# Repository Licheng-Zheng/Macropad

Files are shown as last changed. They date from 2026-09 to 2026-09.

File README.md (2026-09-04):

#### Overview
A custom 9-key mechanical macropad with an OLED display and joystick that is very programmable. It acts as a "Rubber Ducky" which is used to send in commands as if it were a keyboard without relying on any external hardware. 
- Can send multi-character macros entirely on-device without using software like AutoHotkey 
- Key to 81 distinct macro assignments, across 9 different modes 
- OLED display to show the node, joystick position and key presses 
- Under $20 dollars in prorated (I only count a proportion of a cost if I only use a portion of the materials) materials. 
  - If you are looking at this, you probably already have some basic materials at home like wires and raspberry pi picos, so it will likely be significantly cheaper. I only had to spend 5 dollars for this project, and that was because I melted my first raspberry pi. 

 

#### Hardware Limitations 
Because this device is a usb device, they can only send in key presses at the rate that your USB polls. For example, I currently have mine set up to quickly type in a file path that I use frequently, and it takes a couple milliseconds for it to type out. This is due to the fact that USB devices aren't able to paste in things (I think it is due to security reasons). Keyboards can only use the HID protocol, which sends one command every USB polling cycle.  
- To bypass this, you can try using a tool like AutoHotkey, bind one of the keys on the macropad to a key not on the keyboard (F13 to F21), and have it send the command instantly using software. However, in this case, the macropad will only work when that particular software is downloaded on your computer. 
- I personally am ok with the macropad typing everything out, and I would prefer if the macropad didn't rely on a software on my computer to function, so I am just keeping it as is.
- Commercial macropads use software similar to AutoHotkey to send commands, but their softwares are significantly better and have more functionality (opening apps) 

#### Editing the functionality of the Macropad 
1. Changing Keys 
Locate the `MACRO_STRINGS[9][9]` - 9 Lists, each with 9 items. This basically means there are 9 presets, each can have 9 different commands. Mkae sure you are changing it for the right profile.
```
const char* MACRO_STRINGS[9][9] = {
    // Profile 0 (Example: Git Workflow)
    {
        "git status\n", "git add .\n", "git commit -m \"Update\"\n",
        "git push\n",   "git pull\n",  "clear\n",
        "",             "",            ""
    },
```
- You would just type in what string you want the macropad to send in. To press enter, put a `\n` (newline character) after it. 
- You can leave things empty with `""`, and it will just display "UNASSIGNED_KEY" on the OLED screen (nothing gets sent to computer)

2. Changing the Profile Names
There are 9 different possible profiles. 
```
const char* MODE_NAMES[9] = {
    "MODE: EMACS", "MODE: NUMPAD", "MODE: CUSTOM 3", 
    "MODE: CUSTOM 4", "MODE: CUSTOM 5", "MODE: CUSTOM 6", 
    "MODE: CUSTOM 7", "MODE: CUSTOM 8", "MODE: CUSTOM 9"
};
```
You can also change the profile selection in the `MODE_SELECTION_MAP`, but as long as you set up the names properly, this isn't necessary. (also makes it a lot more complicated)

**Chords** 
This is super important, this is how you switch different modes. All three keys must be pressed simultaneously to send teh command. 
- Top row: Recalibrate the joystick 
  - THis polls the joystick 20 times in a couple milliseconds to find where its resting state is at. This then becomes the new "middle" this is helpful if the joystick is slightly off from the middle of `2048`. There is a "deadzone" of 150 where if it is less than 150 away from the middle, no output is registered. 
- Middle row: Turn joystick on or off. 
  - When my soldering wasn't good enough, the joystick would jump around, which would move the mouse around. In case that happens during something important, you can toggle the joystick on or off here. 
- Bottom row: Opens the "Select Profile 1-9" menu, where you can then hit another key to select that particular profile.
- Rightmost column: Turns on the bootloader. 
  - This is essentially you plugging it back in with the bootsel button pressed. It allows it to accept code. 
  - This allows you to upload code without having to open the case again. 
  - Note that this won't work if the raspberry pi pico has crashed (this hasn't happened to me, so not sure what happens next from there)

#### Pinout 
This is how everything needs to be soldered, try not to use much more wire than required, because this makes the case very hard to close. For it to fit in the case that I modelled, headers will need to be removed. 

 

| Component | Module Pin | Pico Connection (GPIO) | Pico Physical Pin | Notes |
| --- | --- | --- | --- | --- |
| **OLED Display** | SDA | GP0 | 1 | I2C0 SDA |
|  | SCL | GP1 | 2 | I2C0 SCL |
|  | VCC | 3V3(OUT) | 36 |  |
|  | GND | GND | 38 |The raspberry pi pico has multiple grounds that can be used |
| **Analog Joystick** | VRx (Horz) | GP26 | 31 | ADC Channel 0 |
|  | VRy (Vert) | GP27 | 32 | GP28 can also be used (for this one or VRx) if the pin is damaged. These are the only pins that can be used because the rapsberry pi pico only has 3 analog pins (the pins that can interpret an analog signal) |
|  | VCC / + | 3V3(OUT) | 36 | Do not use 5V VBUS. This will deliver more power than the joystick can handle and will probably lead to either the joystick or the pico board not functioning anymore |
|  | GND / - | GND | 33 |  |
| **Mechanical Keys** | Top Left | GP9 | 12 | Route the second pin of every switch to a common Ground (GND). This is called daisy chaining. |
|  | Top Middle | GP10 | 14 | For keyboards with more keys, matrices are used with one way diodes. Because we only have 9 mechanical switches and our raspberry pi has more than enough GPIO pins, we don't need to do this.  |
|  | Top Right | GP11 | 15 |  |
|  | Middle Left | GP6 | 9 |  |
|  | Center | GP7 | 10 |  |
|  | Middle Right | GP8 | 11 |  |
|  | Bottom Left | GP3 | 5 |  |
|  | Bottom Middle | GP4 | 6 |  |
|  | Bottom Right | GP5 | 7 |  |

#### CAD Files
These were printed out on my ENder 3 V2 uising white PLA. FOr more details on 3D printing these parts, see `3D_printing_information.md`
Here is the link to the onshape file, details for the purpose of each piece is also found in `3D_printing_information.md`: https://cad.onshape.com/documents/84586ac2eb88b3ac68ec06c5/w/5dcf2d6096f851e748bc3f74/e/13d985377aa5300de055461e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

The STL_Files is for people who don't want to see the models in Onshape and want to print immediately. Some orientation might be required, see `3D_printing_information.md` for how I oriented it. 

I will not be providing my `.uf2` file because everyones needs for a macropad are different, and it requires modifying the `main.cpp` file in order to change its functionality. I will try to create a guide to compiling it for the first time and changing the code. 
For initial testing, I will include the `.uf2` file with just the numpad enabled. 

#### Troubleshooting Guide 
Some of the harder to fix issues that I encountered while making this: 
1. Keys are not mapped properly
   - If they are all sending commands, it means you didn't solder it to the pin outlined in the pinout table above. Fear not!! You can change it in the software so you don't have to resolder anything. You can map the GPIO pin to the correct key switch in `const uint KEY_PINS[9] = {9, 10, 11, 6, 7, 8, 3, 4, 5}; `. 
   - I recommend going into the numpad mode, pressing all the keys (in order), and make the swaps accordingly. 
2. Joystick keeps on dropping lower and lower
   - This meant that my wires were not properly connected to the pico, so the voltage was not getting sent over properly. 
   - Try reseating your wires (heating it up until liquid, and then letting it cool again)
   - I also replaced my first joystick, not sure if that was the issue, but if the carbon track the joystick uses to send its signal to the raspberry pi is broken, the signal will also not work properly 
3. The case is not closing
   - Try unsoldering the wire, cutting it a bit shorter, and make sure they are grouped with similar cables. (I did it where each row of keys had its own bundle) 
   - Use tape to secure it to the bottom of the macropad so it won't get into the way of the spacers that connect the top and bottom halves. 
4. Raspberry pi port doesn't fit into its hole
   - There is a big overhang right above where the port goes, so there is palstic blocking the port from reaching into the hole. 
   - Use a knife to cut away some of the overhanging plastic to get it to fit. Also, only use two screws to hold the raspberry pi pico in, it is more than enough

There are many more issues that I encountered, but the brain has blocked out the trauma and I can't remember some of the issues anymore. 

#### Bill of Materials
| Item | Qty | Description | Cost |
| --- | --- | --- | --- |
| **Raspberry Pi Pico** | 1 | Standard RP2040 microcontroller | $5.00 |
| **Mechanical Switches** | 9 | MX-style switches (Prorated from an $11 50-pack) | $1.98 |
| **Keycaps** | 9 | Numpad keys scavenged from a standard $11 keycap set | ~$2.00 |
| **Analog Joystick Module** | 1 | Standard 5-pin thumbstick module | $3.00 |
| **OLED Display** | 1 | 0.96" 128x64 I2C OLED (SSD1306) | $3.00 |
| **Wire** | 1 | Spool of 28 AWG wire | $3.00 |
| **Fasteners** | 24 | 12x M2 heat set inserts and 12x M2 screws | Scavenged / Assorted |
| **3D Printer Filament** | 96g | PLA at $17/kg. *(Anglers: 8.96g, Top Plate: 23.04g, Bottom Plate: 63.38g, Test Plate: 0.64g)* | $1.63 |
| **USB Cable** | 1 | Data-capable micro-USB cable (Reused from an old phone) | $0.00 ($4.00 new) |
| **Total Prorated Cost** |  |  | **~$19.61** |

The keycaps can also be 3d printed, the stem might is pretty weak and it definitely won't look as great.
This is the printed one I used first which worked pretty well: https://www.printables.com/model/109679-cherry-mx-low-profile-keycap

Hardware lost along the way, you will be remembered: 
- A raspberry pi pico
  - Melted the bootsel button while trying to solder on the ground wire
- A joystick
  - X kept on jumping around. I thought it was due to the carbon track breaking, but it may have been because my wiring was wrong.

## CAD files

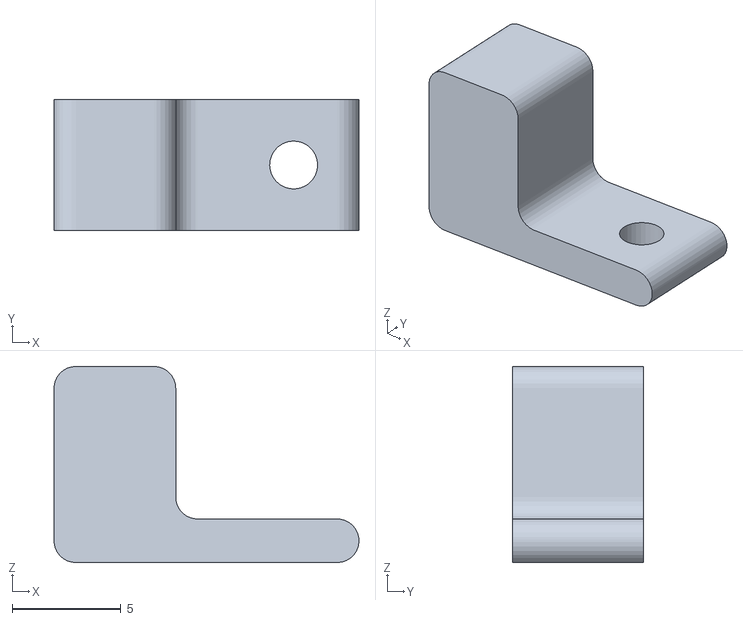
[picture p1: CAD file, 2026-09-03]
STL_Files/OLED_clamp.stl
14.0 x 6.00 x 9.00

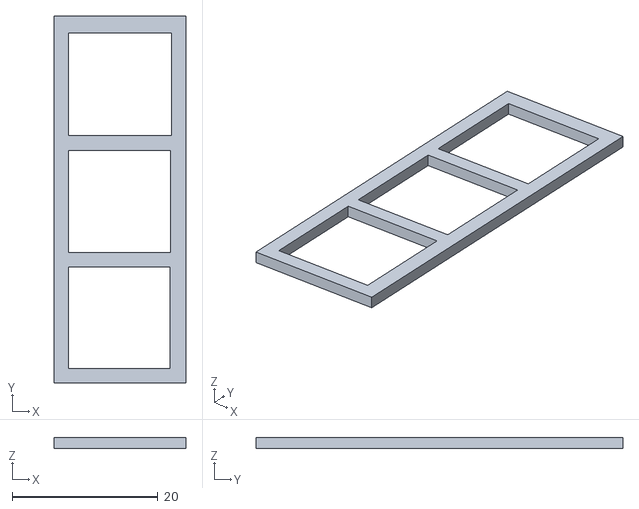
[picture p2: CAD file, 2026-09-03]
STL_Files/tolerance_test_plate.stl
18.1 x 50.3 x 1.50

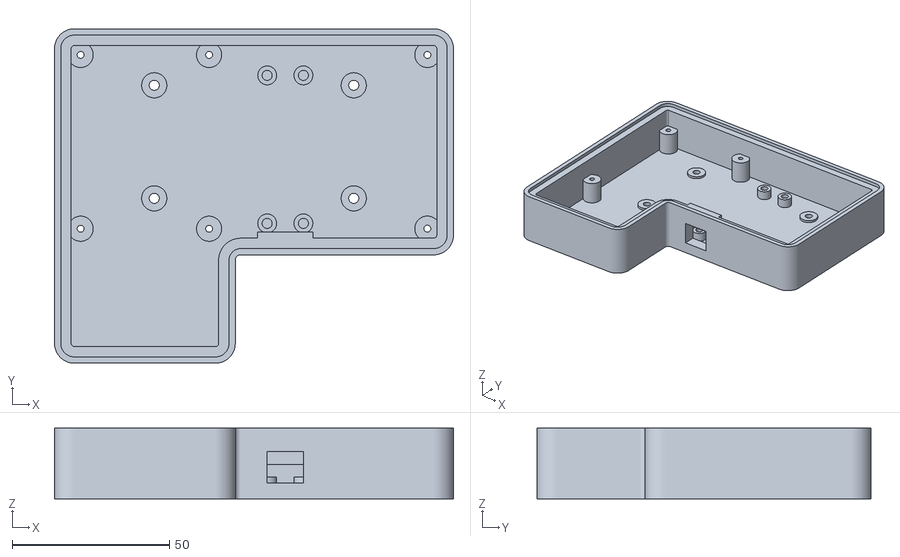
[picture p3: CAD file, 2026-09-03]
STL_Files/BottomPlate.stl
126.7 x 106.2 x 22.5

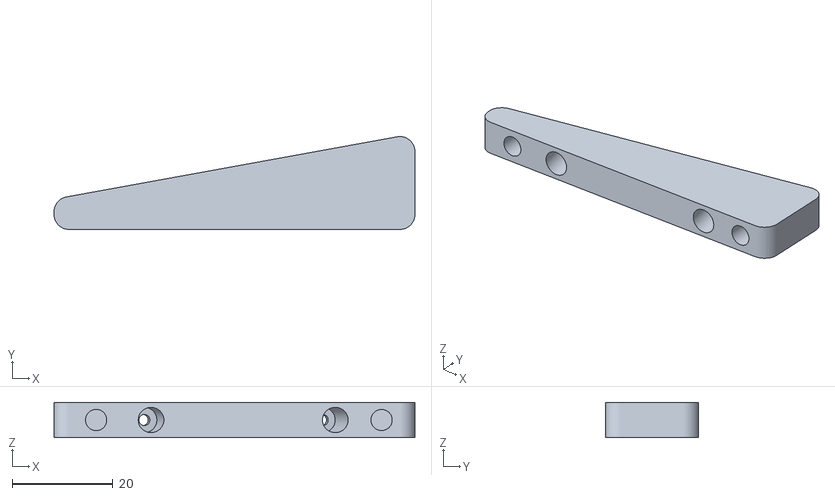
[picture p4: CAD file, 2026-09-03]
STL_Files/angler.stl
71.5 x 18.4 x 7.00

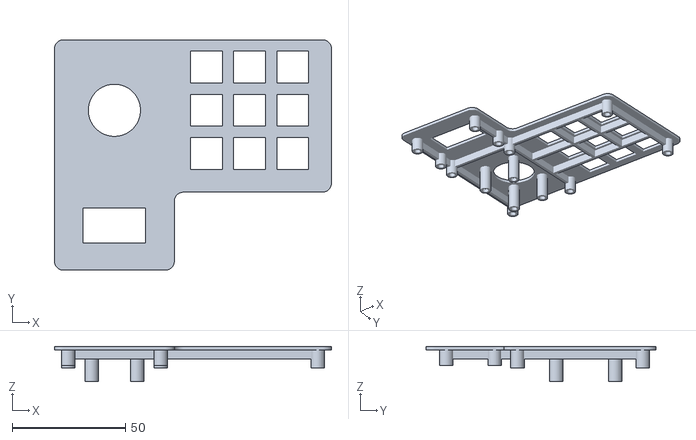
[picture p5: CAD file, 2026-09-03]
STL_Files/Top_plate - Part 1.stl
122.1 x 101.6 x 15.5

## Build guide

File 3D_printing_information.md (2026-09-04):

#### Overview
Here are the different parts that are important in this build. I've included screenshots for each part for how I printed it (I also think that is the best printing orientation, so if you are new to 3D printing, that's how you should do it) 

Everything is printed in White PLA on an Ender 3 V2. I am using the default settings on PrusaSlicer. 

Here are two images that will hopefully help you see how everything goes together:




##### Angler - 8.96 grams of filament
These can be customized to change how far off the ground you want the macropad to stand. Currently, it is at about 8 degrees. They are super interchageable (4 screws hold them in place, so they are not permanently attached)



##### Top Plate - 23.04 grams 
This is where everything is plopped into. Note that you have to put lots of heat set inserts in for this piece. Make sure you see some video tutorials on how they work first so you don't have to reprint. For the key switches, I choose 14.0 mm (which is standard for switches), and they were able to fit well. If your switches are different, you may need to download the onshape file and change it (it can't accomodate too large of a change, so if you have a very unconventional switch, it will probably not render properly) 



##### Bottom Plate - 63.38 grams 
This is where the raspberry pi is screwed into, you may need to cut off some of the port to get the raspberry pi port to fit through. You have to put heat set inserts in the bottom for the anglers to screw into. 




##### Test Plate - 0.64 grams
THis is used to test the different sizes of the switches that your printer creates so you know what size hole you need for the switches. 



##### OLED_Clamp 
This is used to hold the OLED screen to the top plate

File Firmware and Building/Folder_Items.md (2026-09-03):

### Purpose of the folder
This is the folder with all of the code. Everything that is needed to compile the uf2 file (which is what gets brought into the board) is in here. Thereshould be 4 code files in total (see below for what they are). 

After the Raspberry Pi Vscode extension is activated, enter this folder, and click the compile button. THis should create a build file. 
- Within the build file, you will find a uf2 file, this is the code for the macropad. You can edit its function in main.cpp. 
- Unplug the raspberry pi pico, then replug it in while holding the `bootsel` button, this will make it ready to accept code that you send to it. This should make the raspberry pi appear as a drive in your file explorer. 
- Drag the uf2 file from your build folder into the raspberry pi in your file explorer, and it should disapear as a dirve. The code is now uploaded! Hopefully you've completed the soldering, and the macropad is done!

#### CMakeLists.txt
- Defines project details, enables the languages (C, C++, Assembly) used, and their standards 
- IDE integration into the VS code Raspberry Pi Pico extension 
- Sets the target hardware to the original **Raspberry Pi Pico Board**
  - I am not sure if this will also be compatible with the Raspberry Pi Pico 2, or other Raspberry Pis
- Compiles both `main.cpp` (this is where the functionality of the macropad comes from) and `usb_descriptors.c` (this is how the raspberry pi identifies itself to the computer, it is a keyboard and a mouse at the same time)
- Dependencies for the different peripherals are included in here. 
  - I2C is ussed for the OLED display to show the status of the things on screen. 
  - Hardware_pwm: For controlling LED brightness 
  - Hardware_adc: For analog to digital conversion, this is used for the joystick 

The pico_add_extra_outputs is what generates all of the different things that we need to bring into the raspberry pi (including the uf2 file)

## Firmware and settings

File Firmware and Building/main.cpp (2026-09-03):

#include <stdio.h>
#include <string.h>
#include "pico/stdlib.h"
#include "hardware/gpio.h"
#include "hardware/adc.h"
#include "hardware/i2c.h"
#include "bsp/board.h"
#include "tusb.h"
#include "pico/bootrom.h"

// ---------------------------------------------------------
// HARDWARE PIN DEFINITIONS
// ---------------------------------------------------------
const uint KEY_PINS[9] = {9, 10, 11, 6, 7, 8, 3, 4, 5}; 
const uint JOY_X_PIN = 26; 
const uint JOY_Y_PIN = 27; 

#define I2C_PORT i2c0
const uint I2C_SDA = 0;
const uint I2C_SCL = 1;
const uint8_t OLED_ADDR = 0x3C; 

// ---------------------------------------------------------
// ASCII TO HID PARSER
// ---------------------------------------------------------
void get_hid_for_ascii(char c, uint8_t* keycode, uint8_t* modifier) {
    *modifier = 0;
    *keycode = 0;
    
    if (c >= 'a' && c <= 'z') { *keycode = HID_KEY_A + (c - 'a'); }
    else if (c >= 'A' && c <= 'Z') { *keycode = HID_KEY_A + (c - 'A'); *modifier = KEYBOARD_MODIFIER_LEFTSHIFT; }
    else if (c >= '1' && c <= '9') { *keycode = HID_KEY_1 + (c - '1'); }
    else if (c == '0') { *keycode = HID_KEY_0; }
    else if (c == '\n') { *keycode = HID_KEY_ENTER; }
    else if (c == ' ') { *keycode = HID_KEY_SPACE; }
    else if (c == '.') { *keycode = HID_KEY_PERIOD; }
    else if (c == '-') { *keycode = HID_KEY_MINUS; }
    else if (c == '_') { *keycode = HID_KEY_MINUS; *modifier = KEYBOARD_MODIFIER_LEFTSHIFT; }
    else if (c == '/') { *keycode = HID_KEY_SLASH; }
    else if (c == '@') { *keycode = HID_KEY_2; *modifier = KEYBOARD_MODIFIER_LEFTSHIFT; }
    else if (c == ':') { *keycode = HID_KEY_SEMICOLON; *modifier = KEYBOARD_MODIFIER_LEFTSHIFT; }
    else if (c == '!') { *keycode = HID_KEY_1; *modifier = KEYBOARD_MODIFIER_LEFTSHIFT; }
    else if (c == '#') { *keycode = HID_KEY_3; *modifier = KEYBOARD_MODIFIER_LEFTSHIFT; }
    else if (c == '$') { *keycode = HID_KEY_4; *modifier = KEYBOARD_MODIFIER_LEFTSHIFT; }
    else if (c == '%') { *keycode = HID_KEY_5; *modifier = KEYBOARD_MODIFIER_LEFTSHIFT; }
    else if (c == '&') { *keycode = HID_KEY_7; *modifier = KEYBOARD_MODIFIER_LEFTSHIFT; }
    else if (c == '*') { *keycode = HID_KEY_8; *modifier = KEYBOARD_MODIFIER_LEFTSHIFT; }
    else if (c == '(') { *keycode = HID_KEY_9; *modifier = KEYBOARD_MODIFIER_LEFTSHIFT; }
    else if (c == ')') { *keycode = HID_KEY_0; *modifier = KEYBOARD_MODIFIER_LEFTSHIFT; }
    else if (c == '=') { *keycode = HID_KEY_EQUAL; }
    else if (c == '+') { *keycode = HID_KEY_EQUAL; *modifier = KEYBOARD_MODIFIER_LEFTSHIFT; }
    else if (c == '[') { *keycode = HID_KEY_BRACKET_LEFT; }
    else if (c == ']') { *keycode = HID_KEY_BRACKET_RIGHT; }
    else if (c == '{') { *keycode = HID_KEY_BRACKET_LEFT; *modifier = KEYBOARD_MODIFIER_LEFTSHIFT; }
    else if (c == '}') { *keycode = HID_KEY_BRACKET_RIGHT; *modifier = KEYBOARD_MODIFIER_LEFTSHIFT; }
    else if (c == '\\') { *keycode = HID_KEY_BACKSLASH; }
    else if (c == '|') { *keycode = HID_KEY_BACKSLASH; *modifier = KEYBOARD_MODIFIER_LEFTSHIFT; }
    else if (c == ';') { *keycode = HID_KEY_SEMICOLON; }
    else if (c == '\'') { *keycode = HID_KEY_APOSTROPHE; }
    else if (c == '"') { *keycode = HID_KEY_APOSTROPHE; *modifier = KEYBOARD_MODIFIER_LEFTSHIFT; }
    else if (c == ',') { *keycode = HID_KEY_COMMA; }
    else if (c == '<') { *keycode = HID_KEY_COMMA; *modifier = KEYBOARD_MODIFIER_LEFTSHIFT; }
    else if (c == '>') { *keycode = HID_KEY_PERIOD; *modifier = KEYBOARD_MODIFIER_LEFTSHIFT; }
    else if (c == '?') { *keycode = HID_KEY_SLASH; *modifier = KEYBOARD_MODIFIER_LEFTSHIFT; }
    else if (c == '`') { *keycode = HID_KEY_GRAVE; }
    else if (c == '~') { *keycode = HID_KEY_GRAVE; *modifier = KEYBOARD_MODIFIER_LEFTSHIFT; }
}

// ---------------------------------------------------------
// USER CONFIGURATION ZONE (9 PROFILES)
// ---------------------------------------------------------
const char* MACRO_STRINGS[9][9] = {
    // Profile 1: Numpad (Mode 0)
    {
        "7", "8", "9",
        "4", "5", "6",
        "1", "2", "3"
    },
    // Profile 2: Emacs (Mode 1)
    {
    "", "", "",
    "", "", "",
    "", "", ""
    },
    // Profile 3: Custom (Mode 2)
    {
        "", "", "",
        "", "", "",
        "", "", ""
    },
    // Profile 4: Custom (Mode 3)
    {
        "", "", "",
        "", "", "",
        "", "", ""
    },
    // Profile 5: Custom (Mode 4)
    {
        "", "", "",
        "", "", "",
        "", "", ""
    },
    // Profile 6: Custom (Mode 5)
    {
        "", "", "",
        "", "", "",
        "", "", ""
    },
    // Profile 7: Custom (Mode 6)
    {
        "", "", "",
        "", "", "",
        "", "", ""
    },
    // Profile 8: Custom (Mode 7)
    {
        "", "", "",
        "", "", "",
        "", "", ""
    },
    // Profile 9: Custom (Mode 8)
    {
        "", "", "",
        "", "", "",
        "", "", ""
    }
};

const char* MODE_NAMES[9] = {
    "MODE: NUMPAD",   "MODE: EMACS", "MODE: CUSTOM 2", 
    "MODE: CUSTOM 3", "MODE: CUSTOM 4", "MODE: CUSTOM 5", 
    "MODE: CUSTOM 6", "MODE: CUSTOM 7", "MODE: CUSTOM 8"
};

// ---------------------------------------------------------
// PROFILE ROUTING MAP
// ---------------------------------------------------------
// Maps the 9 physical keys to a specific Profile index (0-8)
// Layout: 
// [Top L (Num 7), Top M (Num 8), Top R (Num 9)]
// [Mid L (Num 4), Mid M (Num 5), Mid R (Num 6)]
// [Bot L (Num 1), Bot M (Num 2), Bot R (Num 3)]
const uint8_t MODE_SELECTION_MAP[9] = {
    7, 8, 0,  // Top Row: Maps to Mode 7, Mode 8, Mode 0 (Numpad)
    4, 5, 6,  // Mid Row: Maps to Mode 4, Mode 5, Mode 6
    1, 2, 3   // Bot Row: Maps to Mode 1, Mode 2, Mode 3
};

// ---------------------------------------------------------
// FONT DICTIONARY (Standard 5x7 ASCII)
// ---------------------------------------------------------
static const uint8_t font_5x7[96][5] = {
    {0x00,0x00,0x00,0x00,0x00}, {0x00,0x00,0x5f,0x00,0x00}, {0x00,0x07,0x00,0x07,0x00}, {0x14,0x7f,0x14,0x7f,0x14},
    {0x24,0x2a,0x7f,0x2a,0x12}, {0x23,0x13,0x08,0x64,0x62}, {0x36,0x49,0x55,0x22,0x50}, {0x00,0x05,0x03,0x00,0x00},
    {0x00,0x1c,0x22,0x41,0x00}, {0x00,0x41,0x22,0x1c,0x00}, {0x14,0x08,0x3e,0x08,0x14}, {0x08,0x08,0x3e,0x08,0x08},
    {0x00,0x50,0x30,0x00,0x00}, {0x08,0x08,0x08,0x08,0x08}, {0x00,0x60,0x60,0x00,0x00}, {0x20,0x10,0x08,0x04,0x02},
    {0x3e,0x51,0x49,0x45,0x3e}, {0x00,0x42,0x7f,0x40,0x00}, {0x42,0x61,0x51,0x49,0x46}, {0x21,0x41,0x45,0x4b,0x31},
    {0x18,0x14,0x12,0x7f,0x10}, {0x27,0x45,0x45,0x45,0x39}, {0x3c,0x4a,0x49,0x49,0x30}, {0x01,0x71,0x09,0x05,0x03},
    {0x36,0x49,0x49,0x49,0x36}, {0x06,0x49,0x49,0x29,0x1e}, {0x00,0x36,0x36,0x00,0x00}, {0x00,0x56,0x36,0x00,0x00},
    {0x08,0x14,0x22,0x41,0x00}, {0x14,0x14,0x14,0x14,0x14}, {0x00,0x41,0x22,0x14,0x08}, {0x02,0x01,0x51,0x09,0x06},
    {0x32,0x49,0x79,0x41,0x3e}, {0x7e,0x11,0x11,0x11,0x7e}, {0x7f,0x49,0x49,0x49,0x36}, {0x3e,0x41,0x41,0x41,0x22},
    {0x7f,0x41,0x41,0x22,0x1c}, {0x7f,0x49,0x49,0x49,0x41}, {0x7f,0x09,0x09,0x09,0x01}, {0x3e,0x41,0x49,0x49,0x7a},
    {0x7f,0x08,0x08,0x08,0x7f}, {0x00,0x41,0x7f,0x41,0x00}, {0x20,0x40,0x41,0x3f,0x01}, {0x7f,0x08,0x14,0x22,0x41},
    {0x7f,0x40,0x40,0x40,0x40}, {0x7f,0x02,0x0c,0x02,0x7f}, {0x7f,0x04,0x08,0x10,0x7f}, {0x3e,0x41,0x41,0x41,0x3e},
    {0x7f,0x09,0x09,0x09,0x06}, {0x3e,0x41,0x51,0x21,0x5e}, {0x7f,0x09,0x19,0x29,0x46}, {0x46,0x49,0x49,0x49,0x31},
    {0x01,0x01,0x7f,0x01,0x01}, {0x3f,0x40,0x40,0x40,0x3f}, {0x1f,0x20,0x40,0x20,0x1f}, {0x3f,0x40,0x38,0x40,0x3f},
    {0x63,0x14,0x08,0x14,0x63}, {0x07,0x08,0x70,0x08,0x07}, {0x61,0x51,0x49,0x45,0x43}, {0x00,0x7f,0x41,0x41,0x00},
    {0x02,0x04,0x08,0x10,0x20}, {0x00,0x41,0x41,0x7f,0x00}, {0x04,0x02,0x01,0x02,0x04}, {0x40,0x40,0x40,0x40,0x40},
    {0x00,0x01,0x02,0x04,0x00}, {0x20,0x54,0x54,0x54,0x78}, {0x7f,0x48,0x44,0x44,0x38}, {0x38,0x44,0x44,0x44,0x20},
    {0x38,0x44,0x44,0x48,0x7f}, {0x38,0x54,0x54,0x54,0x18}, {0x08,0x7e,0x09,0x01,0x02}, {0x0c,0x52,0x52,0x52,0x3e},
    {0x7f,0x08,0x04,0x04,0x78}, {0x00,0x44,0x7d,0x40,0x00}, {0x20,0x40,0x44,0x3d,0x00}, {0x7f,0x10,0x28,0x44,0x00},
    {0x00,0x41,0x7f,0x40,0x00}, {0x7c,0x04,0x18,0x04,0x78}, {0x7c,0x08,0x04,0x04,0x78}, {0x38,0x44,0x44,0x44,0x38},
    {0x7c,0x14,0x14,0x14,0x08}, {0x08,0x14,0x14,0x18,0x7c}, {0x7c,0x08,0x04,0x04,0x08}, {0x48,0x54,0x54,0x54,0x20},
    {0x04,0x3f,0x44,0x40,0x20}, {0x3c,0x40,0x40,0x20,0x7c}, {0x1c,0x20,0x40,0x20,0x1c}, {0x3c,0x40,0x30,0x40,0x3c},
    {0x44,0x28,0x10,0x28,0x44}, {0x0c,0x50,0x50,0x50,0x3c}, {0x44,0x64,0x54,0x4c,0x44}, {0x00,0x08,0x36,0x41,0x00},
    {0x00,0x00,0x7f,0x00,0x00}, {0x00,0x41,0x36,0x08,0x00}, {0x10,0x08,0x08,0x10,0x08}, {0x00,0x00,0x00,0x00,0x00}
};

// ---------------------------------------------------------
// OLED DRIVER & GRAPHICS
// ---------------------------------------------------------
uint8_t frame_buffer[1024];

void oled_send_cmd(uint8_t cmd) {
    uint8_t buf[2] = {0x00, cmd}; 
    i2c_write_blocking(I2C_PORT, OLED_ADDR, buf, 2, false);
}

void oled_update() {
    uint8_t payload[1025];
    payload[0] = 0x40; 
    memcpy(&payload[1], frame_buffer, 1024);
    oled_send_cmd(0x21); oled_send_cmd(0); oled_send_cmd(127);
    oled_send_cmd(0x22); oled_send_cmd(0); oled_send_cmd(7);
    i2c_write_blocking(I2C_PORT, OLED_ADDR, payload, 1025, false);
}

void oled_draw_pixel(int x, int y, bool on) {
    if (x < 0 || x >= 128 || y < 0 || y >= 64) return;
    int index = ((y / 8) * 128) + x;
    if (on) frame_buffer[index] |= (1 << (y % 8));
    else    frame_buffer[index] &= ~(1 << (y % 8));
}

void oled_fill_rect(int x, int y, int w, int h, bool on) {
    for (int i = 0; i < w; i++) {
        for (int j = 0; j < h; j++) oled_draw_pixel(x + i, y + j, on);
    }
}

void oled_draw_char(int x, int y, char c, bool color) {
    if (c < 32 || c > 127) return; 
    for (int i = 0; i < 5; i++) {
        uint8_t line = font_5x7[c - 32][i];
        for (int j = 0; j < 7; j++) {
            if (line & 0x01) oled_draw_pixel(x + i, y + j, color);
            line >>= 1;
        }
    }
}

void oled_print(int x, int y, const char* str, bool color = true) {
    while (*str) {
        if (*str == '\n') break; 
        oled_draw_char(x, y, *str, color);
        x += 6; 
        str++;
    }
}

// ---------------------------------------------------------
// TINYUSB REQUIRED CALLBACKS 
// ---------------------------------------------------------
void tud_hid_report_complete_cb(uint8_t instance, uint8_t const* report, uint16_t len) {}
uint16_t tud_hid_get_report_cb(uint8_t instance, uint8_t report_id, hid_report_type_t report_type, uint8_t* buffer, uint16_t reqlen) { return 0; }
void tud_hid_set_report_cb(uint8_t instance, uint8_t report_id, hid_report_type_t report_type, uint8_t const* buffer, uint16_t bufsize) {}

// ---------------------------------------------------------
// HARDWARE INITIALIZATION
// ---------------------------------------------------------
void setup_hardware() {
    board_init(); 
    tusb_init();  
    stdio_init_all();

    for (int i = 0; i < 9; i++) {
        gpio_init(KEY_PINS[i]);
        gpio_set_dir(KEY_PINS[i], GPIO_IN);
        gpio_pull_up(KEY_PINS[i]);
    }

    adc_init();
    adc_gpio_init(JOY_X_PIN);
    adc_gpio_init(JOY_Y_PIN);

    i2c_init(I2C_PORT, 400 * 1000); 
    gpio_set_function(I2C_SDA, GPIO_FUNC_I2C);
    gpio_set_function(I2C_SCL, GPIO_FUNC_I2C);
    gpio_pull_up(I2C_SDA);
    gpio_pull_up(I2C_SCL);

    oled_send_cmd(0xAE); 
    oled_send_cmd(0x20); oled_send_cmd(0x00); 
    oled_send_cmd(0x81); oled_send_cmd(0xFF); 
    oled_send_cmd(0xA1); 
    oled_send_cmd(0xC8); 
    oled_send_cmd(0x8D); oled_send_cmd(0x14); 
    oled_send_cmd(0xAF); 
}

// ---------------------------------------------------------
// MAIN EXECUTION
// ---------------------------------------------------------
int main() {
    setup_hardware();

    const int JOYSTICK_DEADZONE = 150;

    uint32_t cal_x_sum = 0;
    uint32_t cal_y_sum = 0;
    for (int i = 0; i < 10; i++) {
        adc_select_input(0); cal_x_sum += adc_read();
        adc_select_input(1); cal_y_sum += adc_read();
        sleep_ms(10);
    }
    
    uint16_t center_x = cal_x_sum / 10;
    uint16_t center_y = cal_y_sum / 10;

    uint32_t last_oled_update = 0;
    uint32_t last_hid_update = 0;
    
    uint8_t current_mode = 0; 
    
    bool raw_state[9] = {false};
    bool stable_state[9] = {false};
    uint32_t last_edge_time[9] = {0};
    const uint32_t DEBOUNCE_MS = 100;
    
    bool top_chord_was_pressed = false;
    bool mid_chord_was_pressed = false;
    bool bot_chord_was_pressed = false;
    bool right_chord_was_pressed = false;
    
    bool pending_mode_select = false;
    bool waiting_for_chord = false;
    bool can_process_keys = true; 
    uint32_t chord_timer = 0;
    const uint32_t CHORD_WINDOW_MS = 20;

    bool joystick_enabled = false; 
    uint16_t current_joy_x = center_x;
    uint16_t current_joy_y = center_y;
    uint32_t last_joy_action_time = 0;
    bool joy_action_active = false;
    
    int active_key_index = -1;

    const char* active_string = nullptr;
    int string_index = 0;
    bool waiting_for_release_report = false;
    uint32_t last_type_time = 0;

    while (true) {
        tud_task(); 
        uint32_t current_time = to_ms_since_boot(get_absolute_time());

        if (current_time - last_hid_update >= 1) {
            last_hid_update = current_time;

            for (int i = 0; i < 9; i++) {
                bool current_raw = !gpio_get(KEY_PINS[i]);
                if (current_raw != raw_state[i]) {
                    last_edge_time[i] = current_time;
                    raw_state[i] = current_raw;
                }
                if ((current_time - last_edge_time[i]) > DEBOUNCE_MS) {
                    stable_state[i] = current_raw;
                }
            }

            bool all_top_chord_keys = (stable_state[0] && stable_state[1] && stable_state[2]);
            bool all_mid_chord_keys = (stable_state[3] && stable_state[4] && stable_state[5]);
            bool all_bot_chord_keys = (stable_state[6] && stable_state[7] && stable_state[8]);
            bool all_right_chord_keys = (stable_state[2] && stable_state[5] && stable_state[8]);
            
            bool any_top_chord_key = (stable_state[0] || stable_state[1] || stable_state[2]);
            bool any_mid_chord_key = (stable_state[3] || stable_state[4] || stable_state[5]);
            bool any_bot_chord_key = (stable_state[6] || stable_state[7] || stable_state[8]);
            bool any_right_chord_key = (stable_state[2] || stable_state[5] || stable_state[8]);
            bool any_chord_key = (any_top_chord_key || any_mid_chord_key || any_bot_chord_key || any_right_chord_key);

            // Execute Top Chord (Recalibrate Joystick)
            if (all_top_chord_keys && !top_chord_was_pressed && !all_right_chord_keys) {
                top_chord_was_pressed = true;
                waiting_for_chord = false; 
                active_key_index = -1;
                uint32_t recal_x_sum = 0, recal_y_sum = 0;
                for (int i = 0; i < 10; i++) {
                    adc_select_input(0); recal_x_sum += adc_read();
                    adc_select_input(1); recal_y_sum += adc_read();
                    sleep_ms(2); 
                }
                center_x = recal_x_sum / 10;
                center_y = recal_y_sum / 10;
                current_joy_x = center_x;
                current_joy_y = center_y;
                joy_action_active = false;
            } else if (!all_top_chord_keys) top_chord_was_pressed = false;

            // Execute Middle Chord (Joystick Toggle)
            if (all_mid_chord_keys && !mid_chord_was_pressed && !all_right_chord_keys) {
                joystick_enabled = !joystick_enabled; 
                mid_chord_was_pressed = true;
                waiting_for_chord = false; 
                active_key_index = -1;
            } else if (!all_mid_chord_keys) mid_chord_was_pressed = false;

            // Execute Bottom Chord (Enter Mode Selection)
            if (all_bot_chord_keys && !bot_chord_was_pressed && !all_right_chord_keys) {
                bot_chord_was_pressed = true;
                waiting_for_chord = false; 
                active_key_index = -1;
                pending_mode_select = true; 
            } else if (!all_bot_chord_keys) bot_chord_was_pressed = false;

            // Execute Right Chord (BOOTSEL)
            if (all_right_chord_keys && !right_chord_was_pressed) {
                right_chord_was_pressed = true;
                waiting_for_chord = false; 
                active_key_index = -1;
                oled_fill_rect(0, 0, 128, 64, false);
                oled_print(4, 28, "ENTERING BOOTLOADER");
                oled_update();
                sleep_ms(100); 
                reset_usb_boot(0, 0); 
            } else if (!all_right_chord_keys) right_chord_was_pressed = false;

            if (any_chord_key && !top_chord_was_pressed && !mid_chord_was_pressed && !bot_chord_was_pressed && !right_chord_was_pressed && !waiting_for_chord) {
                waiting_for_chord = true;
                chord_timer = current_time;
            }

            can_process_keys = true;
            if (waiting_for_chord) {
                if (current_time - chord_timer < CHORD_WINDOW_MS) can_process_keys = false; 
                else waiting_for_chord = false; 
            }

            adc_select_input(0);
            current_joy_x = adc_read();
            adc_select_input(1);
            current_joy_y = adc_read();

            int joy_x_offset = (int)current_joy_x - (int)center_x;
            int joy_y_offset = (int)current_joy_y - (int)center_y;
            if (joy_x_offset >= -JOYSTICK_DEADZONE && joy_x_offset <= JOYSTICK_DEADZONE) current_joy_x = center_x;
            if (joy_y_offset >= -JOYSTICK_DEADZONE && joy_y_offset <= JOYSTICK_DEADZONE) current_joy_y = center_y;

            if (tud_hid_ready()) {
                if (can_process_keys && !top_chord_was_pressed && !mid_chord_was_pressed && !bot_chord_was_pressed && !right_chord_was_pressed) {
                    bool any_key_pressed = false;
                    for (int i = 0; i < 9; i++) {
                        if (stable_state[i]) {
                            
                            if (pending_mode_select) {
                                if (active_key_index != i) {
                                    current_mode = MODE_SELECTION_MAP[i]; 
                                    pending_mode_select = false;
                                    active_key_index = i; 
                                    active_string = nullptr; 
                                }
                            } else {
                                if (active_key_index != i && active_string == nullptr) {
                                    active_string = MACRO_STRINGS[current_mode][i];
                                    string_index = 0;
                                    waiting_for_release_report = false;
                                    active_key_index = i;
                                }
                            }
                            
                            any_key_pressed = true;
                            break; 
                        }
                    }
                    if (!any_key_pressed) active_key_index = -1;
                }

                if (active_string != nullptr && !pending_mode_select) {
                    if (current_time - last_type_time > 1) {
                        last_type_time = current_time;
                        char c = active_string[string_index];
                        
                        if (c == '\0') {
                            active_string = nullptr;
                            tud_hid_keyboard_report(1, 0, NULL);
                        } else if (waiting_for_release_report) {
                            tud_hid_keyboard_report(1, 0, NULL);
                            waiting_for_release_report = false;
                            string_index++;
                        } else {
                            uint8_t mod = 0, key = 0;
                            get_hid_for_ascii(c, &key, &mod);
                            if (key != 0) {
                                uint8_t keycode_arr[6] = { key };
                                tud_hid_keyboard_report(1, mod, keycode_arr);
                            }
                            waiting_for_release_report = true;
                        }
                    }
                }

                if (joystick_enabled) {
                    int8_t mouse_x = -((int)current_joy_y - (int)center_y) / 128;
                    int8_t mouse_y = ((int)current_joy_x - (int)center_x) / 128;
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

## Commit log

2026-09-03 Completed Macropad
    [BottomPlate.stl, OLED_clamp.stl, Top_plate - Part 1.stl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]
2026-09-03 Update README with Images
    Added images of the finished macropad and internal wiring.
2026-09-03 added images to the 3D printing information document
2026-09-04 assembly image
2026-09-04 Assembly Images
